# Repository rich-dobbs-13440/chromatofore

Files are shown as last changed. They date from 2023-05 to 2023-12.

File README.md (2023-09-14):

# Chromatofore Filament Exchanger - 3D Printable Components

**Description:** 

Chromatofore is a pioneering automatic filament exchanger tailored for entry-level Bowden 3D printers such as the Creality Ender 3 v2 and CR-6 SE. The repository hosts OpenSCAD files that define all parts of the system that need to be 3D printed.

This repository complements the OctoPrint plugin for Chromatofore, allowing users to produce the physical components necessary to benefit from the automatic filament exchanging capabilities the software provides.

## Components Overview

This repository comprises a range of 3D printable components tailored for the Chromatofore Filament Exchanger. The files are structured for ease of printing and assembly, ensuring that even 3D printing novices can assemble their own filament exchanger.

## 3D Printing Guidelines

- **Material Recommendations:** PLA or PETG for optimal strength and durability.
- **Infill:** 20% - 30% recommended for structural parts.
- **Layer Height:** 0.2mm - 0.3mm for best results.
- **Supports:** Check individual part requirements. Some parts may require supports.

## Assembly

1. **Preparation:** Ensure all printed parts are cleaned of any supports or brims.
2. **Components:** Gather all necessary non-printed components (screws, bolts, electronics) as referenced in the assembly guide.
3. **Follow the Assembly Guide:** A step-by-step guide (linked here) will walk you through the assembly process.

## Development Roadmap

*Outlined below are the features and improvements planned for upcoming versions of the Chromatofore 3D components.*

<!-- 
**Version x.x**:
   - Targeted Date: (Date)
   - Expected Features or Improvements: (Brief Description)
-->
(Continue listing planned versions and features)

## Development History

The current state of the Chromatofore components is at **Version: {{CURRENT_VERSION}}**. 

## Current Sprint

(Describe the current sprint's focus)

### Past Sprints

(Start listing past sprints in reverse chronological order)

## Change Log

<!-- 

- **Version x.x (Date)**:
  - Added: New component or modification.
  - Revised: Updated design of an existing component.
  - Removed: Deprecated or replaced components.

(Continue with the list of versions and their respective changes. Always add new entries at the start.)

-->

## Backlog

*Below is a list of acknowledged features, enhancements, and improvements, not yet slated for a specific release.*

- (List items here)

## License

This project is licensed under the MIT License. Please refer to the `LICENSE` file for more details.

## Contribution

Contributions are welcome! Please refer to the `CONTRIBUTING.md` file for guidelines.

## Support and Feedback

For questions, support or feedback, please join our [community forum](#) or open an issue on this repository.

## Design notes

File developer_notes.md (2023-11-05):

# Developer Notes for Chromatofore Filament Exchanger

This document serves as a guide for developers contributing to the `chromatofore` repository. 
It covers our branching strategy and provides commands to help you manage your contributions seamlessly.

## Branching Strategy

For the `chromatofore`, repository we use a feature-branch workflow. 
All development must be done in feature branches, which are created from the `main` branch. 
Direct commits to the `main` branch are not allowed. This ensures that the `main` branch 
always contains stable and deployable code.

### Creating a Feature Branch

To create a new feature branch, first ensure that you are on 
the `main` branch and that you have the latest changes. 
Then, create a new branch. Here's how you can do it:

```bash
# Ensure you're on the main branch
git checkout main

# Fetch the latest changes
git pull

# Create a new feature branch
git checkout -b feature/your-feature-name

git push --set-upstream origin feature/your-feature-name
```

Where `your-feature-name` should be a concise description of the feature or bugfix you're working on.

### Saving Changes in Your Feature Branch

Once you've made changes in your feature branch and want to save them:

Stage all your changes:

```bash
git status 
# Examine output for any new files and then add them if needed.
git add "path to new file"

git commit -am "Describe you changes here"
git push

```

### Merging Your Feature Branch

After you've finished your feature and pushed it to the repository, 
you'll typically create a pull request (PR). Your PR will be reviewed, 
and once approved, it can be merged into the main branch.

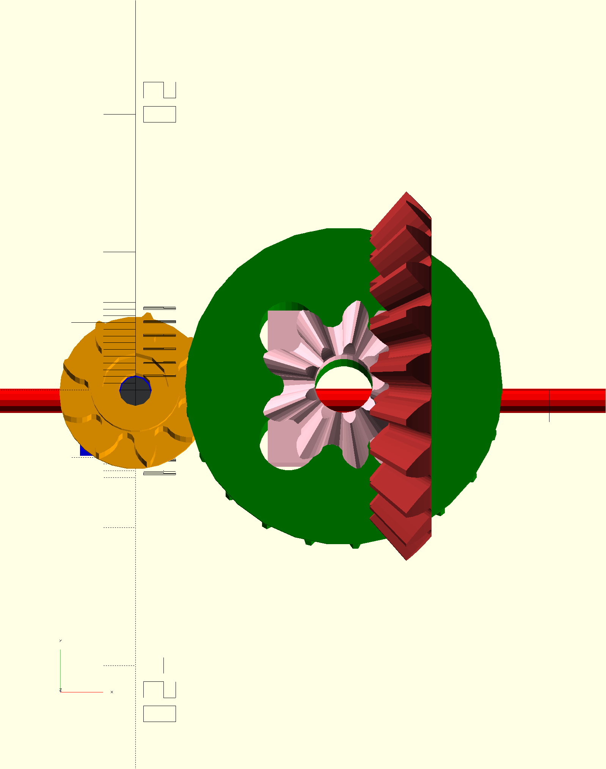
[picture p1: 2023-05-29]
src/inchworm/gearing_top_view.png

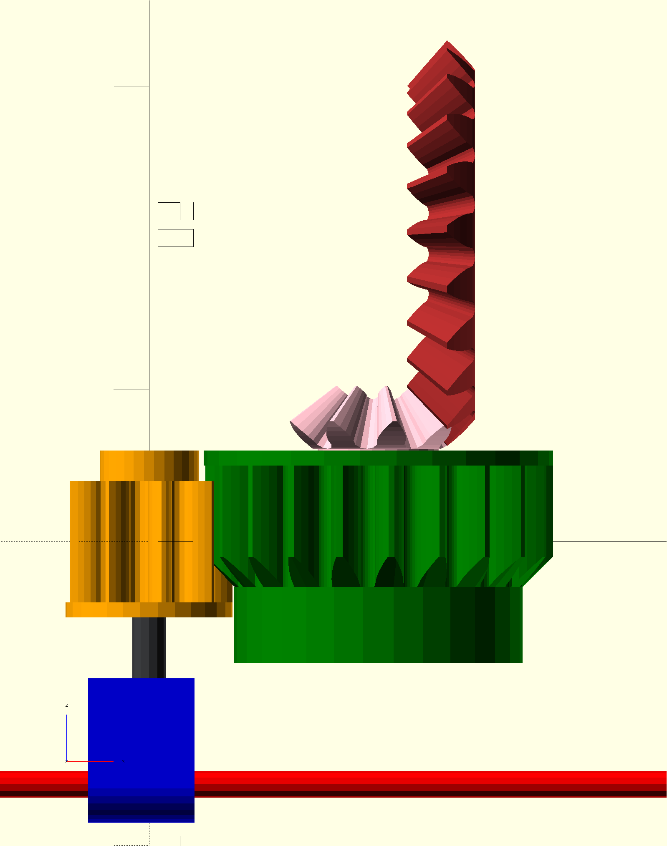
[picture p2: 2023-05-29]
src/inchworm/gearing_side_view.png

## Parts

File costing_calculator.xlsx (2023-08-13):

Configuration | Printer | Quantity | Actuators/Printer | Actuators | PCA9685/Printer | PCF8574/Printer
 | CR 6 SE | 1 | 9 | 9 | 2 | 4
 | Ender 3 V2 | 1 | 9 | 9 | 2 | 4
Total |  | 2 |  | 18 | 4 | 8
Pricing | Item | Price | Quantity/Item | Entity | Price per entity | Quantity for project | Number of items | Cost
 | 9g servo motors | $18.88 | 10 | servo |  | 54 | 6 | $113.28
 | Standard Servo Motor | $15.99 | 2 | servo |  | 2 | 1 | $15.99
 | HiLetGo 2pc PCA9685 | $7.00 | 16 | channel |  | 4 | 4 | $28.00
 | 12PCS PCF8574 IO MCU Expansion Board I2C Interface 8bit | $14.99 | 12 | boards |  | 8 | 1 | $14.99
 | HiLetgo 10pcs Micro Limit Switch KW12-3 AC 250V 5A SPDT 1NO 1NC Micro Switch Normally Open Close Limit Switch with Roller Lever Arm Black | $5.99 | 10 | switch | $0.60 | 36 | 4 | $23.96
 | Arduino Uno R4 Minima | $20.00 | 1 | board | $20.00 | 2 | 2 | $40.00
 | iexcell 400 Pcs M2 x 4/6/8/10/12/14/16/20 Alloy Steel 12.9 Grade High Tensile Hex Socket Head Cap Screws Bolts Nuts Assortment Kit
 | iexcell 400 Pcs M2 x 4/6/8/10/12/14/16/20 Alloy Steel 12.9 Grade High Tensile Hex Socket Head Cap Screws Bolts Nuts Assortment Kit | $11.68 | 1 | kit |  | 1 | 1 | $11.68
 | MUYI 10 Meters = 32.8 Feet PTFE Teflon Tube OD 4mm ID 2mm | $17.99 | 10 | meter | $1.80 | 18 | 2 | $35.98
 | Aclorol 5V 10A 50W Power Supply 100V-240V AC to DC Adapter 5V 10 amp Switching Converter 5.5x2.1mm Plug for WS2811 WS2812B WS2813 5V LED Strip Pixel Lights | $20.00 | 1 | unit | $20.00 | 2 | 2 | $40.00
Total |  | $116.53 |  |  |  |  |  | $247.90

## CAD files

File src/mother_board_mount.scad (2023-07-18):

/* 

Mother board mounting for the Chromatofore system. 

The mother board mounts:
    * an Arduino Uno R4, 
    * the first PCA9685 servo control board,
    * one or two PCF8574 GPIO multiplexer board
    * a medium size bread board cut in half
    
One half of the bread board serves as a I2C bus for the boards. 
The other half is used for connecting to switches and sensors,
as well as installing pull down resistors for switches.

*/
include <ScadStoicheia/centerable.scad>
include <ScadApotheka/material_colors.scad>

use <ScadApotheka/pca9685_slide_rail_mount.scad>
use <ScadApotheka/pcf8574_slide_rail_mount.scad>

a_lot = 100.0  + 0.0;

/* [Output Control] */

fit_test = false;
show_vitamins = true;

/* [Design] */
dy_zero = 6.1; // [0: 0.1 : 10]
pcf8574_first_pin = 12;
pca9685_first_pin = 1;
x_i2c_breadboard = 72.8;

z_breadboard = 11;
x_breadboard = 83.7;
y_half_breadboard = 29;
z_base_connector = 2;
// Set to make the holes on the breadboard to match up with the pins on the GPIO board!
dz_extra_under_board = 1.5; // [0:0.1:2]

dx_underwriters_knot = 25;
dx_strain_relief_2 = 90;
dx_strain_relief_1 = dx_strain_relief_2 - dx_underwriters_knot;
dx_strain_relief_base = 61;
z_strain_relief = 16;
z_strain_relief_base = 3;
d_power_cord = 2.9;


dy_bread_board_support = 28;
dy_arduino_connection = 15;
module end_of_customization() {}


dy_pcf8574 = (pcf8574_first_pin + 1.5) * 0.1 * 25.4 + dy_zero;
dy_pca9685 = (pca9685_first_pin + 2.5) * 0.1 * 25.4 + dy_zero;


module base() {
    module under_i2c_bus() {
        extent = [z_breadboard, x_i2c_breadboard, z_base_connector];
        color(PART_17) block(extent, center=ABOVE+RIGHT+BEHIND);
    }
    module between_slides() {
        translate([0, 2*dy_pca9685, 0]) block([62, 2, 8 + dz_extra_under_board], center=ABOVE+FRONT);
    }
    module behind_gpio_breadboard() {
        dx = x_breadboard + 5;
        dy = dy_pcf8574 + 9;
        extent = [4, y_half_breadboard, z_breadboard];
        color(PART_23) {
            translate([dx, dy, 0]) {
                block(extent, center=ABOVE+RIGHT+BEHIND);
            }
        }
    }
    module power_strain_relief() {
        color(PART_21) {
            x_sr = dx_strain_relief_2 - dx_strain_relief_base;
            strain_relief_block = [4, 2*dy_pca9685 + 2, z_strain_relief];
            dz_holes = (strain_relief_block.z - z_strain_relief_base)/2 + z_strain_relief_base;
            render(convexity=10) difference() {
                union() {
                    translate([dx_strain_relief_base, 0, 0]) block([x_sr, 2*dy_pca9685 +2, z_strain_relief_base], center=ABOVE+RIGHT+FRONT);
                    translate([dx_strain_relief_1, 0, 0]) block(strain_relief_block, center=ABOVE+RIGHT+FRONT);
                    translate([dx_strain_relief_2, 0, 0]) block(strain_relief_block, center=ABOVE+RIGHT+FRONT);
                }
                // Vertical slits for each strand internally
                translate([dx_strain_relief_1, strain_relief_block.y/2 + 3, dz_holes]) {
                    center_reflect([0, 1, 0]) translate([0, 5]) {
                        hull() {
                            rod(d = d_power_cord, l=4*strain_relief_block.x);
                            translate([0, 0, strain_relief_block.z]) rod(d = d_power_cord, l=4*strain_relief_block.x);
                        }
                    }
                } 
                // Horizontal pill shaped hole for the two parallel strands, for the external connection
                translate([dx_strain_relief_2, strain_relief_block.y/2, dz_holes]) {
                    hull() center_reflect([0, 1, 0]) translate([0, d_power_cord/2]) rod(d = d_power_cord, l=4*strain_relief_block.x);
                }
                // Holes for mounting
                dx_mounting = (dx_strain_relief_1 + dx_strain_relief_2)/2 + strain_relief_block.x/2;
                translate([dx_mounting, strain_relief_block.y/2, 0]) {
                    center_reflect([0, 1, 0]) translate([0, 10, 25]) hole_through("M2", cld=0.4, $fn=12);
                }
            }
        }
    }
    module connector() {
        // The connector allows installing support and securing of I2C bus breadboard,
        // and allows connecting the Arduino support. 
        // For development, initially these parts might be printed separately, although
        // later they might also be printed as one object. 
        extent = [6, x_i2c_breadboard, 6];
        dx = -z_breadboard - extent.x/2;
        dy = extent.y/2;
        translate([ dx, dy, 0]) {
            color(PART_16) {
                render(convexity=10) difference() {
                    block(extent, center=ABOVE);
                    center_reflect([0, 1, 0]) {
                        rotate([180, 0, 0]) translate([0, dy_bread_board_support, 2]) {
                            hole_through("M2", h=4, cld=0.4, $fn=12);
                        }
                    }
                    center_reflect([0, 1, 0]) {
                        translate([0, dy_arduino_connection, 25]) {
                            hole_through("M2", cld=0.4, $fn=12);
                        }
                    }                    
                }
            }
        }
    }
    translate([0, dy_pcf8574, 0]) 
        pcf8574_slide_rail_mount(
            board_count=2, 
            dz_extra_under_board = dz_extra_under_board,
            center=FRONT, 
            show_vitamins=show_vitamins);
    translate([0, dy_pca9685, 0]) 
        pca9685_slide_rail_mount(
            center=FRONT, 
            slide_from_left = true,
            dz_extra_under_board = dz_extra_under_board,
            show_vitamins=show_vitamins);
    between_slides();
    under_i2c_bus();
    connector();
    behind_gpio_breadboard();
    power_strain_relief();
    
}




if (fit_test) {
    difference() {
        base();
        translate([10, 0, 0]) plane_clearance(FRONT);
    }
} else {
    base();
}

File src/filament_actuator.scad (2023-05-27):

include <lib/logging.scad>
include <lib/centerable.scad>
use <lib/shapes.scad>
use <lib/not_included_batteries.scad>
include <nutsnbolts-master/cyl_head_bolt.scad>
include <nutsnbolts-master/data-metric_cyl_head_bolts.scad>
include <MCAD/servos.scad>
use <lib/ptfe_tubing.scad>

/* [Output Control] */

orient_for_build = false;

show_mocks = true;

build_end_caps = true;
build_ptfe_glides = true;
build_packing_gland_face = true;
build_packing_gland = true;
build_traveller = true;

test_fit = false;


/* [Actuator Design] */

actuator_range_of_motion = 50; // [10 : 1: 100]
d_clamp_screw = 3; //[2, 2.5, 3, 4, 5, 6]
l_clamp_screw = 8; //[4, 5, 6, 8, 10, 12]
clamp_screw_family = str("M", d_clamp_screw); // [M2, M2.5, M3, M4, M5, M6]
echo("clamp_screw_family", clamp_screw_family);
clamp_screw_name = str("M", d_clamp_screw, "x", l_clamp_screw);
echo("clamp_screw_name", clamp_screw_name);


y_packing_gland = 2;

packing_gland_id = 4.1; // [4.0, 4.05, 4.1, 4.15, 4.2, 4.25]
packing_gland_count = 2;
x_clamping_interference = 0.5;

x_side = 8;
y_side = 6;
ptfe_engagement = 1;

module end_of_customization() {}

filament_diameter = 1.75;
ptfe_diameter = 4;

df = _get_fam(clamp_screw_family);
echo("df", df);
nutkey = df[_NB_F_NUT_KEY];
echo("nutkey", nutkey);
nutheight = df[_NB_F_NUT_HEIGHT];
echo("nutheight", nutheight);

front_wall = 2;
gap_between_nut_and_filament = 1;
x_traveller_front = nutheight + front_wall + gap_between_nut_and_filament + filament_diameter/2;
y_traveller_front = nutkey + 8;
gap_to_slide = 3;
slide_engagement = 1;
x_traveller_behind = filament_diameter/2 + gap_to_slide + slide_engagement;
y_traveller_behind = ptfe_diameter - .5;
dz_screw_for_traveller = nutkey ;
z_traveller = 20; 
screw_offset = 3;

a_lot = 1000;

z_end_cap  =  10;
dy_screws = 5;    
faceplate_screw_translation = [0, dy_screws, z_end_cap-3];


packing_gland_face = [10, y_packing_gland, 20];

// slide_extra, as well as extra for clearance.
// Guess for now!
slide_extra = 5;
cage_length_half_length = actuator_range_of_motion/2 + z_traveller + z_end_cap;
slide_length = actuator_range_of_motion + z_traveller + slide_extra;
gland_translation = [0, cage_length_half_length+1, -1];

module filament_clearance() {
    can(d=2, h=200);
}

module face_plate_screw_clearance() { 
    center_reflect([0, 1, 0]) 
        translate(faceplate_screw_translation) 
            rotate([180, 0, 0]) 
                hole_through("M2", cld=0.2, $fn=12);  
    center_reflect([0, 1, 0]) 
        translate(faceplate_screw_translation + [0, 2, 0]) 
            rotate([0, 0, 90]) 
                nutcatch_sidecut("M2", clh=.5);        
}




module ptfe_tube_packing_clearance() {
    translate([0, 0, z_end_cap]) {
        can(d = 5, taper=6, h=4, center=BELOW, rank=10);
        can(d = 4.0, taper=4.5, h=z_end_cap, center=BELOW, rank=10);
    }
}

module packing_gland(orient_for_build,  id=4.0, face_thickness = 1) {   
    module shape() {
        difference() {
            union() {
                can(d = 6, taper=5, h=4, center=ABOVE);
                can(d = 8, h=face_thickness, center=BELOW);
            }
            can(d=id, h=a_lot);
        }
    }
    if (orient_for_build) {
        translate([0, 0, face_thickness]) rotate([0, 0, 0]) shape();
    } else {
        translate([0, 0, -cage_length_half_length]) shape();
        translate([0, 0, cage_length_half_length]) rotate([180, 0, 0]) shape();
    }
}

   
module end_block() {
    x = 10;
    z = 10;
    render(convexity=10) difference() {
        block([x, y_end_block, z], center=ABOVE+RIGHT);
        filament_clearance(); 
        ptfe_tube_packing_clearance();

        center_reflect([1, 0, 0]) translate([dx_screws, 2.5, 25]) hole_through("M2", cld=0.2, $fn=12);
        face_plate_screw_clearance();
    }
}

module end_cap(orient_for_build) {
    module blank() {
        translate([0, 0, z_end_cap/2]) {
            hull() {
                {
                    glide_placement() {
                        rotate([0, 0, -135]) glide_block(h=z_end_cap);
                        rotate([0, 0, 0]) glide_block(h=z_end_cap);
                    }
                }
                block([5, 15, z_end_cap]); // Space for packing gland screws and nuts
            }
        }
    }
    module shape() {
        z_glide = 100;
        difference() {
            blank();
            filament_clearance(); 
            ptfe_tube_packing_clearance();
            face_plate_screw_clearance();
            glide_placement() {
                        rotate([0, 0, -135]) glide_end_cap(as_clearance=true);
                        rotate([0, 0, 0]) glide_end_cap(as_clearance=true);
            }            
        }
        
    }
    if (orient_for_build) {
        translate([0, 0, z_end_cap]) rotate([180, 0, 0]) shape();
    } else {
        center_reflect([0, 0, 1]) translate([0, 0, slide_length/2]) shape();
    }
}


module packing_gland_face(orient_for_build) {
    dz_filament = 100;
    module located_shape() {
        difference() {
            translate(gland_translation) block(packing_gland_face, center=ABOVE+RIGHT);
            face_plate_screw_clearance();
            translate([0, 0, dz_filament]) rotate([90, 0, 0]) can(d = 4.5, h=a_lot, rank=10);
        }
    } 
    if (orient_for_build) {
        translate([0, gland_translation.y + 10, 0] ) rotate([90, 0 , 0]) translate(-gland_translation) located_shape();
        translate([0, gland_translation.y + 20, 0] ) rotate([90, 0 , 0]) translate(-gland_translation) located_shape();
    } else {
        located_shape();
    }     
}


module ptfe_tube_as_slide(h, as_clearance, clearance=0.2, ) {
    hollow = as_clearance ? 0 : 2.0;
    actual_clearance = as_clearance ? clearance: 0;
    color("white") can(d=ptfe_diameter + 2 * actual_clearance, hollow=hollow, h=h);
}





module glide_end_cap(as_clearance, clearance = 0.2) {
    actual_clearance = as_clearance ? clearance : 0;
    translate([ptfe_engagement-0.01, 0, 0]) {
       difference() {
           hull() {
               translate([0, 0, -actual_clearance]) block([x_side, y_side, 2*screw_offset], center=BEHIND+ABOVE);
               translate([-actual_clearance, 0, 2*screw_offset + actual_clearance]) 
                    block([x_side + 2 * actual_clearance, y_side+1 + 2*actual_clearance, 0.01], center=BEHIND+BELOW);
           }
           if (!as_clearance) {
               translate([4, 0, screw_offset]) rotate([0, 90, 0]) hole_through("M2", cld=0.2, $fn=12);
           }
       }
       if (as_clearance) {
           translate([4, 0, screw_offset]) rotate([0, 90, 0]) hole_through("M2", cld=0.2, $fn=12);
       }
   } 
}

module glide_block(h) {
    translate([ptfe_engagement, 0, 0]) block([x_side, y_side, h], center=BEHIND);
}

module ptfe_glide(h, orient_for_build = false, angle=0, as_clearance=true) {
    assert(is_num(h));
    z_capture = ptfe_diameter/2 - 1.5 + 0.75;

    
    module screw_clearance() {
        center_reflect([0, 0, 1]) 
            translate([5, 0, h/2 + screw_offset]) 
                rotate([0, 90, 0]) hole_through("M2", $fn=12, cld=0.2);
    }
    module shape(as_clearance) {
        color("green") {
            rotate([0, 0, angle]) {
                difference() {
                    glide_block(h); 
                    ptfe_tube_as_slide(h=h, as_clearance = true);
                }
                center_reflect([0, 0, 1]) translate([0, 0, h/2]) glide_end_cap(as_clearance = false);
            }
            if (as_clearance) {
                ptfe_tube_as_slide(h=h, as_clearance = true);
            }
            
        }
    }
    if (!orient_for_build && !as_clearance) {
        ptfe_tube_as_slide(h=h, as_clearance = false);
    } 
    if (orient_for_build) {
        translate([0, 0, x_side-ptfe_engagement]) rotate([0, -90, 90]) shape(as_clearance=false);
    } else {
        shape(as_clearance=as_clearance);
    }
}

module glide_placement() {
    center_reflect([0, 1, 0]) 
        translate([x_traveller_front, y_traveller_front/2, 0]) 
            children(0);
    translate([-x_traveller_behind - ptfe_diameter/2 + slide_engagement, 0, 0]) 
        children(1);
}



module ptfe_glides(h=100, as_clearance=false) {
    glide_placement() {
        ptfe_glide(h = h, as_clearance = as_clearance, angle=-135);
        ptfe_glide(h = h, as_clearance = as_clearance);
    }        
}
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

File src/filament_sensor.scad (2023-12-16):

/* It looks like this version is obsolete and broken.*/ 


include <ScadStoicheia/centerable.scad>
use <ScadStoicheia/shapes.scad>
use <ScadStoicheia/visualization.scad>
include <ScadApotheka/material_colors.scad>
use <ScadApotheka/no_solder_roller_limit_switch_holder.scad>
use <ScadApotheka/ptfe_tubing_quick_connect.scad> 

NEW_DEVELOPMENT = 0 + 0;
DESIGNING = 1 + 0;
ASSEMBLE_SUBCOMPONENTS = 3 + 0;
PRINTING = 4 + 0;

/* [Output Control] */

    mode = 3; // [1:"Designing, no rotation or translation", 3: "Assemble", 4: "Printing"]
    show_vitamins = true;
    guide = 1; // [1:Solid, 0.25:Ghostly, 0:"Invisible, won't print" ]
    base = 1; // [1:Solid, 0.25:Ghostly, 0:"Invisible, won't print" ]
    qc_body = 1; // [1:Solid, 0.25:Ghostly, 0:"Invisible, won't print" ]
    copies_to_print = 1; // [1:10]

/* [Design] */
    use_ferrule_clamping = true;
    dz_filament = -14;
    dx_roller = -6;
    dz_roller = 1; // [0:0.1:2]
    filament_clearance = 0.5;
    d_roller_clearance = 5.5;
    l_roller_clearance = 5.; // [4:0.1:6]
    dx_mount_holes = 5;
    dy_outlet_screw_offset = 8;
    dx_flange = 16;

/* [Build Plate Layout] */
    x_guide_bp = 10; 
    y_guide_bp = 0; 
    dx_guide_bp = 30;

    x_base_bp = 0;
    y_base_bp = -20;
    dx_base_bp = 30;

    x_qc_body_bp = 0;
    y_qc_body_bp = 30;
    dx_qc_body_bp = 30;

module end_customization() {}


    a_lot = 100 + 0.1;
    d_filament = 1.75;
    filament_length = 50;
    outlet_flange = [2, 2*dy_outlet_screw_offset+6, 6];

    function back_plate() = [1, 1, 1];
    function back_plate_translation() = [10, 10, 10];

    l_guide = back_plate().x + 2*dx_flange;
    guide_base = [l_guide, back_plate_translation().y, 10];

if (mode == PRINTING) {
    for (item = [0:copies_to_print-1]) {
        filament_sensor_base(item);
        filament_guide(item);  
        quick_connect_body_outlet(item);      
    }
} else {
    filament_sensor_base();
    filament_guide();
    quick_connect_body_outlet();
}

function layout_from_mode(mode) = 
    mode == NEW_DEVELOPMENT ? "hidden" :
    mode == DESIGNING ? "as_designed" :
    //mode == MESHING_GEARS ? "mesh_gears" :
    mode == ASSEMBLE_SUBCOMPONENTS ? "assemble" :
    mode == PRINTING ? "printing" :
    "unknown";

layout = layout_from_mode(mode);

show_parts = true;

visualization_guide = 
    visualize_info(
        "Filament Sensor Guide", PART_32, guide, layout, show_parts); 

visualization_base = 
    visualize_info(
        "Filament Sensor Base", PART_34, base, layout, show_parts); 

visualization_qc_body = 
    visualize_info(
        "Quick Connect Body", PART_29, qc_body, layout, show_parts); 
        
module filament(as_clearance=false) {
    translate([0, 0, dz_filament]) {
        if (as_clearance) {
             rod(d=d_filament + 2 * filament_clearance, l = a_lot);
        } else {
            color("red") rod(d=d_filament, l = filament_length);
        }
    }
}

module outlet_mounting_screws(as_clearance = false) {
    translate([0, 0, dz_filament]) {
        center_reflect([0, 1, 0]) {
            translate([0, dy_outlet_screw_offset, 0]) {
                rotate([0, 90, 0]) {    
                    if (as_clearance) {
                        translate([0, 0, 50])  hole_through("M2", $fn=12, cld=0.4, l=100);
                    } else {
                    }  
                }
            }
        }  
    }
}

module quick_connect_body_outlet(item) {
    module mounting_screws(as_clearance = false) {
        translate([0, 0, 0]) {
            center_reflect([0, 1, 0]) {
                translate([0, dy_outlet_screw_offset, 0]) {
                    rotate([0, 0, 90]) {    
                        if (as_clearance) {
                            translate([0, 0, 3])  hole_through("M2", l=15, cld=0.4,  $fn=12);                            
                        } else {
                            color(STAINLESS_STEEL) screw("M2x12", $fn=12);
                            color(BLACK_IRON)translate([0, 0, -10]) nut("M2", $fn=12);
                        }  
                    }
                }
            }  
        }   
    } 
    module blank() {
        quick_connect_body(orient_for_build=true);
        translate([0, 0, -outlet_flange.x/2]) rotate([0, 90, 0]) block(outlet_flange + [0, 0, 6]);
    }
    module shape() {
        render(convexity=10) difference() {
            blank();
            mounting_screws(as_clearance=true);
            can(d = d_filament + 2 * filament_clearance, h = filament_length);
        }
    }
    dz_printing = outlet_flange.x;  
    rotation = 
        mode == PRINTING ? [0, 0, 0] : [0, 90, 0];
    translation = 
        mode == PRINTING ? [x_qc_body_bp + item * dx_qc_body_bp, y_qc_body_bp, dz_printing] : 
        [guide_base.x/2 + outlet_flange.x, 0, dz_filament];
    translate(translation) {
        rotate(rotation) {
            if (show_vitamins && mode != PRINTING) {
                mounting_screws();
            }
            visualize(visualization_qc_body)  shape();
        }
    }
}

module filament_guide(item=0) {
    dx_flange_printing = -dy_outlet_screw_offset-4;
    d_guide_tube = 2*back_plate_translation().y; 
    module blank() {
        translate([0, 0, dz_filament]) {
            rod(d=d_guide_tube, l=l_guide);
            block(guide_base, center=BELOW+RIGHT);
            center_reflect([1, 0, 0]) translate([l_guide/2, 0, 0]) {
                hull() {
                    block(outlet_flange, center=BEHIND);
                    translate([dx_flange_printing, 0, 0]) rod(d=d_guide_tube, l=0.1);
                }
            }
        }
    }
    module roller_clearance() {
        translate([dx_roller, 0, dz_filament+dz_roller]) {
            hull() {
                rod(d=d_roller_clearance, l = l_roller_clearance, center=SIDEWISE);
                translate([0, 0, d_roller_clearance/2]) block([d_roller_clearance+3, l_roller_clearance + 4, 0.1], center=ABOVE);
            } 
        }
    }  
    module reentry_clearance() {
        translate([dx_roller, 0, dz_filament]) {
            hull() {
                rod(d=2*d_filament+2, l = l_roller_clearance+1);
                rod(d=d_filament, l = l_roller_clearance + 5);
            }
        }
    }  
    module shape() {
        render(convexity=10) difference() {
            blank();
            filament(as_clearance=true);
            reentry_clearance();
            roller_clearance();
            guide_mounting_screws(as_clearance=true, as_slot=true); 
            outlet_mounting_screws(as_clearance=true);
        }
    }
    dz_printing = l_guide/2;  
    rotation = 
        mode == PRINTING ? [0, 90, 0] : [0, 0, 0];
    translation = 
        mode == PRINTING ? [x_guide_bp + item * dx_guide_bp, y_guide_bp, dz_printing] : 
        [0, 0, 0];
    translate(translation) {
        rotate(rotation) {
            visualize(visualization_guide)  shape();
        }
    }
}

module guide_mounting_screws(as_clearance=false, as_slot=true) {
    dx=4;
    dz_mount_holes = dz_filament -6;
    center_reflect([1, 0, 0]) {
        translate([dx_mount_holes, 0, dz_mount_holes]) {
            rotate([90, 0, 0]) {
                if (as_clearance) {
                    if (as_slot) {
                        hull() {
                            translate([-3, 0, 25])  hole_through("M2", $fn=12, cld=0.4);
                            translate([dx, 0, 25]) hole_through("M2", $fn=12, cld=0.4);
                        }
                    } else { 
                        translate([dx/2, 0, 25]) hole_through("M2", $fn=12, cld=0.4);                    
                    }
                } else {
                    color(STAINLESS_STEEL) {
                        translate([dx/2, 0, 0]) screw("M2x10", $fn=12);
                        translate([dx/2, 0, -7.5]) nut("M2", $fn=12);
                    }
                }
            }
        }
    }    
}

module filament_sensor_base(item=0) {
    z_be = -dz_filament + 6;
    wall = 4;
    module base_extension() {
        render(convexity=10) difference() {
             translate(back_plate_translation()) {
                block([back_plate().x, wall, z_be], center=BELOW+RIGHT);
             }
             guide_mounting_screws(as_clearance=true); 
        }   
    }
    if (show_vitamins && mode != PRINTING) {
        filament(as_clearance=false);
        guide_mounting_screws(as_clearance=false); 
    }
    rotation = 
        mode == PRINTING ? [-90, 0, 0] :
         [0, 0, 0];
    dz_printing = back_plate_translation().y + wall ;
    translation = 
        mode == PRINTING ? [x_base_bp + item * dx_base_bp, y_base_bp, dz_printing] : 
        [0, 0, 0];    
    if (base > 0) {
        translate(translation) {
            rotate(rotation) {
                // use_ferrules=use_ferrule_clamping
                nsrsh_terminal_end_clamp(, show_vitamins=show_vitamins && mode != PRINTING);
                color(PART_34) base_extension();
            }
        }
    }
}

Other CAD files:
src/cr6se/wrasse_extruder_lever_actuator.scad
src/cr6se/cr6se_filament_guide.scad
src/cr6se/light_dimmer_filament_detector_adapter.scad
src/earwig/earwig.scad
src/ender3v2/ender3v2_extruder_release_lever.scad
src/ender3v2/ender3v2_filament_guide.scad
src/ender3v2/ender3v2_raspberry_pi_cana_case_mount.scad
src/ender3v2/ender3v2_z_axis_mocks.scad
src/ender3v2/ender3v2_z_stop_adjuster.scad
src/filament_sharpener.scad
src/inchworm/filament_clamp.scad
src/inchworm/inch_worm_filament_actuator.scad
src/inchworm/planetary_filament_clamp.scad
src/mantis/mantis.scad
src/medusa/medusa_filament_detector.scad
src/medusa/medusa_filament_gateway.scad
src/skate_bearing_filament_spool_holder.scad

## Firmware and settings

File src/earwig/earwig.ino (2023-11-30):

/*

GCODE implementation:

G28 C0 : Move clamp servo to home position signaled by limit switch.  

G1 E10 F10 : Extrude 10 mm of filament, feed rate currently ignore.

G1 C10  : Move clamp servo to an angle of 10 degrees

G1 X10  : Move move servo to an angle of 10 degres

*/


#include <TimeLib.h>
#include <Servo.h>
#include <string.h>
#include <ezButton.h>
#include <math.h>
//#include <earwig.h>


float flt_nan = sqrt(-1);


// Servo pins
const int FILAMENT_MOVE_PIN = 8;
const int FILAMENT_CLAMP_PIN = 9;
const int FILAMENT_ROTATE_PIN = 10;
const int EXTRUDER_ENGAGE_PIN = 11;
const int FILAMENT_FIXED_CLAMP_PIN = 12;

// Servo objects
Servo filamentMoveServo;
Servo filamentClampServo;
Servo filamentRotateServo;
Servo extruderEngageServo;


// Servo angles
static int filamentMoveAngle = 90;
static int filamentClampAngle = 90;
static int filamentRotateAngle = 180;
static int extruderEngageAngle = 0;


static bool enableMoveServo = true;  // Axis X
static bool enableClampServo = true; // Axis C
static bool enableRotateServo = false;
static bool enableEngageServo = false;

const int CLAMP_LIMIT_PIN = 12;
ezButton clampLimitSwitch(CLAMP_LIMIT_PIN);  // create ezButton object that attach to pin 7;

int unclamp_angle = 10;
int clamp_angle = 170;

const int redLedPin = 14;
const int blueLedPin = 15;

unsigned long previousMillisLedHeartBeat = 0;
unsigned long previousMillisSerial = 0;  // Update the previousMillis value
int heartbeatPin = redLedPin;

int baudRate = 9600;
unsigned long ledHeartBeatInterval = 500;  // Time interval in milliseconds (1 second)
unsigned long intervalSerial = 20000;      // Time interval in milliseconds (1 second)
int ledHeatBeatState = LOW;                // Initial LED state

bool serialIsAvailable = false;

static const char* logPrefix = "-- debug --";

const int BUFFER_SIZE = 256;    // Size of the input buffer
char inputBuffer[BUFFER_SIZE];  // Input buffer to store characters
int bufferIndex = 0;            // Index to keep track of the buffer position

template<typename T, typename... Args>
void debugLog(T first, Args... args) {
  Serial.print(logPrefix);
  Serial.print(" ");
  Serial.print(first);
  ((Serial.print(" "), Serial.print(args)), ...);
  Serial.println();
}


// Function to update filament move angle
void updateFilamentMoveAngle(int angle) {
  if (enableMoveServo) {
    filamentMoveAngle = angle;
    filamentMoveServo.write(filamentMoveAngle);
  }
}

// Function to update filament clamp angle
void updateFilamentClampAngle(const int angle) {
  if (enableMoveServo) {
    filamentClampAngle = angle;
    filamentClampServo.write(filamentClampAngle);
    debugLog("Current filamentClampAngle", filamentClampAngle);
  }
}

// Function to update filament rotate angle
void updateFilamentRotateAngle(const int angle) {
  if (enableRotateServo) {
    filamentRotateAngle = angle;
    filamentRotateServo.write(filamentRotateAngle);
  }
}

// Function to update extruder engage angle
void updateExtruderEngageAngle(const int angle) {
  if (enableEngageServo) {
    extruderEngageAngle = angle;
    extruderEngageServo.write(extruderEngageAngle);
  }
}




void acknowledgeCommand(const String& command) {
  // Calculate the checksum
  byte checksum = calculateChecksum(command);

  Serial.print("OK");
  Serial.print(" ");
  Serial.println(checksum, HEX);
  Serial.flush();
}

byte calculateChecksum(const String& command) {
  byte checksum = 0;
  for (size_t i = 0; i < command.length(); i++) {
    checksum ^= command[i];
  }
  return checksum;
}



void writePeriodicMessage() {
  // Get the current time
  int currentHour = hour();
  int currentMinute = minute();
  int currentSecond = second();

  int state = clampLimitSwitch.getState();
  String message;
  if (state == HIGH)
    message = "The clamp limit switch: UNTOUCHED";
  else
    message = "The clamp limit switch: TOUCHED";

  // Display the periodic message with the current time
  debugLog("Current time: ", currentHour, ":", currentMinute, ":", currentSecond, message);
  Serial.flush();
}




void ledHeartBeat() {
  unsigned long currentMillis = millis();

  // Check if the specified interval has elapsed
  if (currentMillis - previousMillisLedHeartBeat >= ledHeartBeatInterval) {
    previousMillisLedHeartBeat = currentMillis;

    // Toggle the state of the red LED
    if (ledHeatBeatState == LOW) {
      ledHeatBeatState = HIGH;
    } else {
      ledHeatBeatState = LOW;
    }

    digitalWrite(heartbeatPin, ledHeatBeatState);  // Update the LED state
  }
}


void serialHeartBeat() {
  unsigned long currentMillis = millis();
  if (currentMillis - previousMillisSerial >= intervalSerial) {
    previousMillisSerial = currentMillis;  // Update the previousMillis value
    writePeriodicMessage();
  }
}

void extrude(const float mm_of_filament, const float feedrate_mm_per_minute) {
  if (mm_of_filament > 0) {
    updateFilamentClampAngle(unclamp_angle);
    delay(2000);  // Time interval to allow  clamp to open
    updateFilamentMoveAngle(0);
    delay(2000);  // Time interval to allow  traveller to get into position
    updateFilamentClampAngle(clamp_angle);
    // Ignore feedrate for now!
    updateFilamentMoveAngle(mm_of_filament);
    delay(4000);
  } else {
    updateFilamentClampAngle(unclamp_angle);  // Unclamp
    delay(2000);                              // Time interval to allow  clamp to open
    updateFilamentMoveAngle(135);
    delay(2000);                            // Time interval to allow  traveller to get into position
    updateFilamentClampAngle(clamp_angle);  // Clamp
    // Ignore feedrate for now!
    updateFilamentMoveAngle(135 + mm_of_filament);
    delay(4000);
  }
}


void home_clamp_servo() {
  float increment = 1;
  float clamp_angle = 90;
  delay(1000);
  updateFilamentClampAngle(clamp_angle);
  clampLimitSwitch.loop();
  while(clampLimitSwitch.getState() == LOW) {
    delay(1000);
    clampLimitSwitch.loop();
  }
  for (clamp_angle = 90; clamp_angle < 180; clamp_angle += increment) {
    updateFilamentClampAngle(clamp_angle);
    clampLimitSwitch.loop();
    int state = clampLimitSwitch.getState();
    if (state == LOW) {
      break;
    }
  }
  debugLog("Fast find clamp limit:", clamp_angle);
}



void handleSerial() {
  if (Serial.available() > 0) {
    digitalWrite(blueLedPin, HIGH);
    char serialChar = Serial.read();

    if (serialChar != '\n' && serialChar != '\r') {
      // Add character to the buffer
      inputBuffer[bufferIndex] = serialChar;
      bufferIndex++;

      // Check if buffer is full
      if (bufferIndex >= BUFFER_SIZE - 1) {
        inputBuffer[bufferIndex] = '\0';  // Null-terminate the buffer
        bufferIndex = 0;                  // Reset buffer index
        processInputBuffer();             // Process the received line
      }
    } else {
      // Line ending character encountered
      inputBuffer[bufferIndex] = '\0';  // Null-terminate the buffer
      bufferIndex = 0;                  // Reset buffer index
      processInputBuffer();             // Process the received line
    }
    digitalWrite(blueLedPin, LOW);
  }
}



void processInputBuffer() {
  String gcode_line(inputBuffer);
  acknowledgeCommand(gcode_line);
  debugLog("Received ", gcode_line);
  char* token;
  char delimiter = ' ';
  token = strtok(inputBuffer, &delimiter);
  
  float c = flt_nan;
  float e = flt_nan;
  float f = flt_nan;
  float g = flt_nan;
  float x = flt_nan;

  //debugLog("e", e);
  while (token != NULL) {
    String word = token;
    //debugLog("word", word);
    if (word.startsWith("C")) {
      c = word.substring(1).toFloat();
    } else if (word.startsWith("E")) {
      e = word.substring(1).toFloat();
    } else if (word.startsWith("E")) {
      e = word.substring(1).toFloat();
    } else if (word.startsWith("F")) {
      f = word.substring(1).toFloat();
    } else if (word.startsWith("G")) {
      g = word.substring(1).toFloat();
    } else if (word.startsWith("X")) {
      x = word.substring(1).toFloat();      
    } 
    token = strtok(NULL, &delimiter);
  }
  // debugLog("c:", c);
  // debugLog("e:", e);
  // debugLog("f:", f);
  // debugLog("g:", g);

  switch (int(g)) {
    case 1:
      if (!isnan(c)) {
        debugLog("Handle clamp command. Angle:", c);
        float angle = c;
        updateFilamentClampAngle(angle);
      }      
      if (!isnan(e)) {
        debugLog("Handle extrusion command.");
        float mm_of_filament = e;
        float feedrate_mm_per_minute = f;
        extrude(mm_of_filament, feedrate_mm_per_minute);
      }
      if (!isnan(x)) {
        debugLog("Handle move command. Angle:", x);
        float angle = x;
        updateFilamentMoveAngle(angle);
      }

      break;
    case 10:
      // Code to execute when g is 10.0
      debugLog("Value of g is 10");
      break;
    case 28:
      // Home axis
      if (c != 0) {
        home_clamp_servo();
      }
      break;
    default:
      // Code to execute when g doesn't match any case
      debugLog("Value of g doesn't match any case");
      break;
  }
}

void setupServos() {
  if (enableMoveServo) {
    filamentMoveServo.attach(FILAMENT_MOVE_PIN);
  }
  if (enableClampServo) {
    clampLimitSwitch.setDebounceTime(50);  // set debounce time to 50 milliseconds
    filamentClampServo.attach(FILAMENT_CLAMP_PIN);
  }
  if (enableRotateServo) {
    filamentRotateServo.attach(FILAMENT_ROTATE_PIN);
  }
  if (enableEngageServo) {
    extruderEngageServo.attach(EXTRUDER_ENGAGE_PIN);
  }

  // Set initial servo angles
  updateFilamentMoveAngle(filamentMoveAngle);
  updateFilamentClampAngle(filamentClampAngle);
  updateFilamentRotateAngle(filamentRotateAngle);
  updateExtruderEngageAngle(extruderEngageAngle);

  delay(10000);
}

void setupSerial() {
  Serial.begin(baudRate);

  debugLog("--------------");
  debugLog("Sketch Version: 1.1");
  debugLog("Upload Date: ", __DATE__);
  debugLog("Upload Time: ", __TIME__);
  debugLog("Baud Rate: ", baudRate);
  debugLog("Millis: ", millis());
}

void setupLedHeartBeat(const int pin) {
  heartbeatPin = pin;
  pinMode(heartbeatPin, OUTPUT);
}

void setup() {

  // Initialize the digital pin as an output
  pinMode(redLedPin, OUTPUT);
  pinMode(blueLedPin, OUTPUT);

  setupLedHeartBeat(redLedPin);

  digitalWrite(redLedPin, HIGH);
  setupSerial();
  digitalWrite(redLedPin, LOW);

  digitalWrite(blueLedPin, HIGH);
  enableMoveServo = true;
  enableClampServo = true;
  enableRotateServo = true;
  enableEngageServo = true;
  setupServos();
  digitalWrite(blueLedPin, LOW);
}

void loop() {
  clampLimitSwitch.loop();
  if (clampLimitSwitch.isPressed())
    debugLog("The limit switch: UNTOUCHED -> TOUCHED");

  if (clampLimitSwitch.isReleased())
    debugLog("The limit switch: TOUCHED -> UNTOUCHED");
  ledHeartBeat();
  serialHeartBeat();
  handleSerial();
}

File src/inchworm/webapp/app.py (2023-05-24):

from flask import Flask, render_template
from flask import request
import serial
import time


class InchwormException(RuntimeError):
    pass

class ChecksumMismatchException(InchwormException):
    pass

class InvalidResponseException(InchwormException):
    pass


app = Flask(__name__)

# @app.route('/')
# def index():
#     return render_template('index.html')

# def send_command_to_arduino(command):
#     # Configure the serial port
#     port = '/dev/ttyACM0'  # Change this to match your Arduino's port
#     baud_rate = 9600  # Set the baud rate to match your Arduino's configuration

#     # Open the serial port
#     ser = serial.Serial(port, baud_rate)

#     # Send the command to Arduino
#     ser.write(command.encode())

#     # Read the response from Arduino
#     response = ser.readline()
#     print("Response:", response.decode())

#     # Close the serial port
#     ser.close()



# def send_command_to_arduino(command):
#     port = '/dev/ttyACM0'  # Change this to match your Arduino's port
#     baud_rate = 9600  # Set the baud rate to match your Arduino's configuration

#     with serial.Serial(port, baud_rate, timeout=1) as ser:
#         # Send the command to Arduino
#         ser.write(command.encode())

#         # Read the response from Arduino
#         response = read_response(ser)


def send_command_to_arduino(command):
    # Configure the serial port
    port = '/dev/ttyACM0'  # Change this to match your Arduino's port
    baud_rate = 9600  # Set the baud rate to match your Arduino's configuration

    # Open the serial port
    with serial.Serial(port, baud_rate, timeout=10) as ser:

        # Send the command to Arduino
        ser.write(command.encode())

        # Read the response from Arduino
        arduino_response = read_response(ser)

        return arduino_response
    



# def read_response(ser):
#     response = ""
#     checksum = 0

#     # Read lines until the "ok" message is received
#     while True:
#         line = ser.readline().decode().strip()
#         if line.startswith("ok"):
#             # Parse the line to extract the verb and checksum
#             parts = line.split()
#             verb = parts[0]
#             received_checksum = int(parts[1])

#             # Check if the received checksum matches the calculated checksum
#             if received_checksum != calculate_checksum(response):
#                 raise Exception("Checksum mismatch")

#             if verb == "ok":
#                 return response
#             else:
#                 raise Exception("Invalid response: {}".format(line))
#         else:
#             response += line

#         # Update the checksum
#         for char in line:
#             checksum ^= ord(char)

def read_response(ser):
    response = ""

    # Read lines until the "ok" message is received
    timeout = 30
    start_time = time.time()
    while True:
        line = ser.readline().decode().strip()
        print(f"Arduino response: {line}")
        if line.startswith("ok"):
            # Parse the line to extract the verb and checksum
            parts = line.split()
            verb = parts[0]
            received_checksum = int(parts[1])
            print(f"Arduino received_checksum: {received_checksum}")

            # Check if the received checksum matches the calculated checksum
            if received_checksum != calculate_checksum(response):
                raise ChecksumMismatchException("Checksum mismatch")
            return response

        else:
            response += line

        elapsed_time = time.time() - start_time
        if elapsed_time >= timeout:
            raise TimeoutError()            


def calculate_checksum(data):
    checksum = 0
    for char in data:
        checksum ^= ord(char)
    return checksum

# # Example usage
# command = "G1 X100 Y100"
# response = send_command_to_arduino(command)
# print("Response:", response)           


@app.route('/', methods=['GET', 'POST'])
def index():
    if request.method == 'POST':
        if 'extrude' in request.form:
            # Perform the extrusion action here
            # Add your extrusion code or function call
            print("Extrusion initiated!")
            extrude = 'G1 E10'  # Example extrusion command 
            try:
                response = send_command_to_arduino(extrude)
                print("Response:", response)
                print("Extrusion completed:")
            except ChecksumMismatchException as e:
                print("Checksum mismatch:", str(e))
            except InvalidResponseException as e:
                print("Invalid response:", str(e))
            except InchwormException as e:
                print("An InchwormException occurred:", str(e))
            except TimeoutError:
                print("Timeout error")

    return render_template('index.html')


if __name__ == '__main__':
    app.debug = True
    app.run(host='0.0.0.0', port=5000, debug=True)

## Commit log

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2023-05-22 Coupling is functional. Working on drive gear, to make it small for gearing to servo.
    [bearing_shaft_coupling.stl, inch_worm_filament_actuator.scad]
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2023-05-23 Second printing of gear. Gear module was wrong. Too many teeth, shaft not long enough
    [inch_worm_filament_actuator.scad]
2023-05-23 Gear calculations for modulus, number of teeth for a given axle spacing
    [inch_worm_filament_actuator.scad, triangular_bearing_shaft.scad]
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2023-05-27 Check in because not sure if actuator code modification in IDE are desired:
    [inch_worm_filament_actuator.scad]
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2023-05-29 Working on gearing. Increased bevel gear module, to get a more printable gear.
    [filament_clamp.scad]
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2023-05-30 Third print of retaining clip. Refined geometry to try to make assembly easier
    [planetary_filament_clamp.scad]
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2023-05-31 Test print drive gear with retainer screws spaced for easy entire access. Resulted in too big a gear. Check in prior to changing sizing calcs
    [filament_clamp.scad, planetary_filament_clamp.scad]
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2023-06-01 Working on a temporary space to be able to assemble to existing shaft
    [planetary_filament_clamp.scad]
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2023-06-03 Working on drive gear retainer sizing and clearances
    [planetary_filament_clamp.scad]
2023-06-04 Working on implementing a slide that is just screws and PTFE. Nothing printed.
    [planetary_filament_clamp.scad]
2023-06-04 Implemented layout for printing, fitting all pieces onto build plate for one shot printing.
    [planetary_filament_clamp.scad]
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2023-06-06 Adjust clamp screw retainer for more play and clearance
    [planetary_filament_clamp.scad]
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2023-07-04 Start working on earwig actuator - minimal one based on 9g servos
    [earwig.scad]
2023-07-04 Fix problem with cam not being on build plate
    [earwig.scad]
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2023-07-05 Work on interference between linkage screw head and horn
    [earwig.scad]
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2023-07-06 Make horn linkange short by putting it alongside horn
    [earwig.scad]
2023-07-06 Fine tune horn cam to hold onto horn better, Should help with loading filament
    [earwig.scad]
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2023-07-06 Update build plate layout for recent changes so that build in one fell swoop is regained
    [earwig.scad]
2023-07-07 Second iteration on pusher base. More clearance for horn linkage. Taper entrance to quick connect
    [earwig.scad]
2023-07-07 Add quick connect collet and clip to print layout. Refined layout for printing
    [earwig.scad]
2023-07-07 Third iteration on pusher body - move quick connect further away to allow greater range of rotation of horn linkage
    [earwig.scad]
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2023-07-07 Work on alternate horn cam with side insertion for better filament loading
    [earwig.scad]
2023-07-07 Changes to filament guide, horn cam to try to increase clamping force
    [earwig.scad]
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2023-07-08 Develop costing calculator to estimate cost for equipping printers with filament changers.
    [costing_calculator.xlsx]
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2023-07-13 Fix screw hole that didn't go completely through
    [filament_sensor.scad]
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2023-07-18 Rearrange board layout for easier routing of power cable, add strain relief for power cable.
    [mother_board_mount.scad]
2023-07-24 Initial print of limit switch holder for fixed clamp
    [earwig.scad]
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2023-07-25 Move limit switch up against servo, so mounting plate is on the outside
    [earwig.scad]
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2023-07-28 Implemented fixed clamp body with slot for ptfe clamp, for part reduction and better retention of outlet ptfe tubing
    [earwig.scad]
2023-07-28 Reworking limit switch so it doesn't stich out so far
    [earwig.scad]
2023-07-28 Rework limit switch bumper to be compatible with revised limit switch holder
    [earwig.scad]
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2023-07-30 Start work on integrating quarter turn tubing connector into fixed clamp body
    [earwig.scad]
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2023-07-31 Implement unified moving clamp body. Wider for less binding. Filament entrances for easier loading
    [earwig.scad]
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2023-08-02 Start working on the junction that combines the filament detectors and that uses the quarter turn fittings
    [costing_calculator.xlsx, medusa_filament_gateway.scad]
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2023-08-03 More work on the cone - now only missing opening for limit switch
    [medusa_filament_gateway.scad]
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2023-08-04 Second iteration on filament detector. Adjustment, clearance, and support changes.
    [medusa_filament_detector.scad, medusa_filament_gateway.scad]
2023-08-04 Third iteration on filament detector. Align adjustment screw with limit switch arm
    [medusa_filament_detector.scad, medusa_filament_gateway.scad]
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2023-08-04 Add ability to rotate keyholes to reduce interference between sensors
    [medusa_filament_gateway.scad]
2023-08-04 Add a adjust screw nut block to filament holder to provide better adjust to triggering roller switch
    [medusa_filament_detector.scad]
2023-08-04 Adjust filament path for check for insertability. Add ability to look at cross section.
    [medusa_filament_gateway.scad]
2023-08-05 Added ability to tilt filament detectors allowing stacking of multiplexers and a straighter filament path
    [medusa_filament_gateway.scad]
2023-08-09 Revise filament detector to use adjustable mount for fine-tuning when detector triggers
    [medusa_filament_detector.scad, medusa_filament_gateway.scad]
2023-08-09 Making detector stiffer by adding material near roller clearance. Also refactoring
    [medusa_filament_detector.scad]
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2023-08-09 Stronger attachment of mount to filament path - Last print allowed mount to twist off
    [medusa_filament_detector.scad]
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2023-08-12 Gateway seems workable. Switching over to provide a filament loader for earwig
    [earwig.scad, medusa_filament_detector.scad, medusa_filament_gateway.scad]
2023-08-12 Redesign horn cam for bidirectional clamping action.
    [earwig.scad]
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2023-08-13 Still working at refining geometry of filament holder clip and bow tip
    [earwig.scad]
2023-08-13 Working on integrating filament holder into fixed clamp body
    [earwig.scad]
2023-08-14 Working fine tuning filament holder clip fit with fixed clamp body
    [earwig.scad]
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2023-08-15 Trying to get filament holder to clip into pusher body with right amount of force
    [earwig.scad]
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2023-08-24 Rework horn cam for easier insertion and robustness of 3d printed part
    [earwig.scad]
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2023-09-15 Tapered cam blank. Cam is pushing filament down and out. Easier printing
    [earwig.scad]
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2023-11-05 Fix accidental modification of a variable
    [earwig.scad]
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2023-11-07 Remove some of the obsolete code from the redesign
    [mantis.scad]
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2023-11-17 Revise clamp cam so that it clamps over 180 degree of rotation.
    [mantis.scad]
2023-11-18 Revised filament guide to move filament near center of rotation of servo
    [mantis.scad]
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2023-11-18 Cam surface calculations are parameterized with customization - cam seems like it is locking filament now
    [mantis.scad]
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2023-11-19 Fix bug with printing transformations for slider base and position sensor
    [mantis.scad]
2023-11-19 Working on fixed clamp filament guide
    [mantis.scad]
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2023-11-20 Fix problem with printing pusher assembly
    [mantis.scad]
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2023-11-22 Working on printing out pusher with it stronger but still prints ok
    [mantis.scad]
2023-11-22 Mouse ears on moving clamp bracket & changes to driver link geometry
    [mantis.scad]
2023-11-23 Some refinements of driver link geomtry drive by interference with limit switch
    [mantis.scad]
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2023-11-23 Revise driver and couple link geometry for greater range of rotation and less material usage
    [mantis.scad]
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2023-11-30 Revise horn clip geometry for better clearance of release lever
    [wrasse_extruder_lever_actuator.scad]
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2023-11-30 Next print of horn extension - add in clearances to adjust fit with horn
    [wrasse_extruder_lever_actuator.scad]
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2023-12-02 Reimplement pusher using a pin that is engaged or disengaged by lowering or lifting
    [wrasse_extruder_lever_actuator.scad]
2023-12-02 Revise to make cap fit over back of extruder. Stronger puller printing orientation
    [wrasse_extruder_lever_actuator.scad]
2023-12-02 Clearance for pusher and puller pins, trim puller pin for better printability
    [wrasse_extruder_lever_actuator.scad]
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2023-12-03 Test print 2 - more horn extension clearance
    [wrasse_extruder_lever_actuator.scad]
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2023-12-04 Shift servo location and shorten radius for puller pin location
    [wrasse_extruder_lever_actuator.scad]
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2023-12-07 Improve support for printing curved surface on back side of horn extension
    [wrasse_extruder_lever_actuator.scad]
2023-12-10 Increase clearance for puller pin in zip tie servo mount
    [wrasse_extruder_lever_actuator.scad]
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2023-12-12 Add flute collet inlet to the filament guide, for attachment to Medusa
    [cr6se_filament_guide.scad, mantis.scad]
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2023-12-14 Working on redesign of Mantis support - first print snapped on usage
    [cr6se_filament_guide.scad]
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2023-12-26 More clearance above IR sensor
    [mantis.scad]
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
